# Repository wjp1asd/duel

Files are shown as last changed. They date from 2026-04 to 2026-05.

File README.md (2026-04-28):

# 🎴 DuelDisk-ESP32 | 决斗盘 ESP32

<p align="center">
  <strong>A Wi-Fi-controllable duel disk system powered by ESP32 & MicroPython</strong><br>
  基于 ESP32 + MicroPython 的 WiFi 控制智能决斗盘
</p>

---
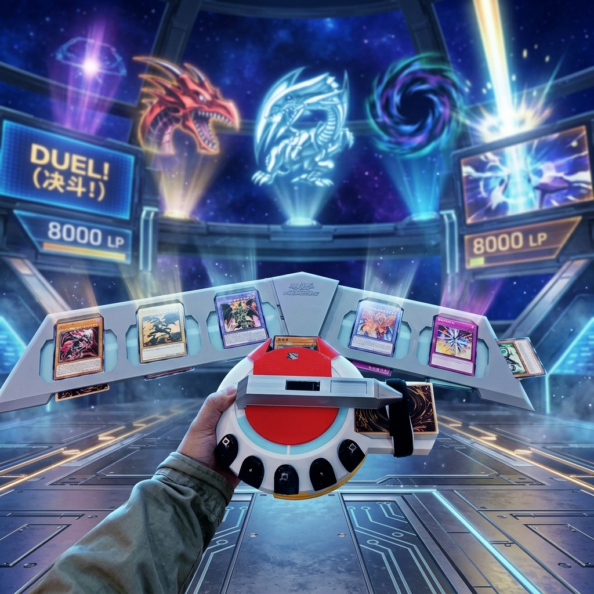
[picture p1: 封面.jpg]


## 🇨🇳 中文介绍

### 项目简介

本项目是一个基于 ESP32 的智能决斗盘系统，灵感来自经典卡牌对战游戏。通过 ESP32 微控制器集成 OLED 显示、舵机控制、音频播放、WS2812 灯光、RFID 读卡等功能，并通过 WiFi AP 模式提供网页控制界面，实现远程操控。
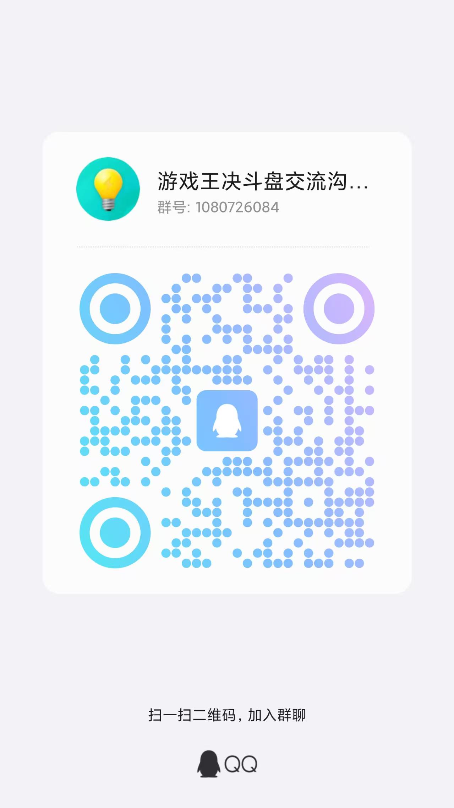
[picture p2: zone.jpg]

群里进行一些技术指导，和招募一些有能力的小伙伴，一起做智能眼镜终极版，早日完成童年梦想，同时也欢迎资源加入，如硬件供应，广告等，募集一些资金为爱发电。
虽然本项目开源，大家可以尽情创作，还是希望二道贩子可以声明一下出处，请等最终版发布再开始搬运。

音乐资源链接：https://pan.quark.cn/s/7ec613fa6839
### ✨ 功能特性

| 功能模块 | 说明 |
|---|---|
| 🖥️ OLED 显示 | SSD1306 128x32 OLED，支持 LP 生命值老虎机滚动动画 |
| 🎵 音频系统 | DFPlayer Mini，支持音效播放、随机背景音乐、音量调节 |
| 💡 WS2812 灯带 | 双灯带（各 30 珠），支持常亮 / 彩虹 / 呼吸 / 音乐闪烁 |
| 📡 WiFi 控制 | AP 热点模式（192.168.4.1），网页控制 LP、音乐、灯光、音量 |
| 🔧 舵机控制 | 机械爪开合控制 |
| 📋 RFID 读卡 | RC522 射频模块，支持 Mifare 1K 卡片 UID 读取 |

### 🔗 引脚分配

```
![](接线图.png)
┌─────────────────────────────────────────┐
│              ESP32 引脚映射              │
├─────────────┬─────────────┬─────────────┤
│    模块      │    引脚     │   GPIO      │
├─────────────┼─────────────┼─────────────┤
│ OLED SDA    │ I2C 数据    │ GPIO 5      │
│ OLED SCL    │ I2C 时钟    │ GPIO 17     │
│ DFPlayer TX │ UART 发送   │ GPIO 13     │
│ DFPlayer RX │ UART 接收   │ GPIO 12     │
│ WS2812 灯带1│ 数据        │ GPIO 27     │
│ WS2812 灯带2│ 数据        │ GPIO 14     │
└─────────────┴─────────────┴─────────────┘
```

### 📱 网页控制

连接 ESP32 的 WiFi 热点后，访问 `192.168.4.1` 即可打开控制面板：

- **LP 控制**：修改双方生命值，支持一键重置
- **音乐播放**：选择指定曲目或随机背景音乐
- **灯光模式**：切换灯带颜色和模式（常亮/彩虹/呼吸/关闭）
- **音量调节**：滑块 + 快捷按钮（±1/±5）

### 📁 项目结构

```
duel_project/
├── main.py          # 主程序（AP + Web Server + LED + 控制）
├── config.py        # 引脚与网络配置
├── audio.py         # DFPlayer Mini 音频控制
├── servo.py         # 舵机控制
├── oled_big.py      # OLED 大字体显示
├── ssd1306.py       # SSD1306 驱动
├── mfrc522.py       # RC522 RFID 驱动
├── rfid.py          # RFID 读卡逻辑
├── rmt.py           # 红外发射
├── boot.py          # 启动脚本
└── duel_net.py      # WiFi 网络模块（STA 模式预留）
```

### 🛠️ 快速开始

**1. 环境准备**
- ESP32 开发板
- MicroPython 固件（v1.28+）
- Thonny IDE 或 mpremote 工具

**2. 烧录固件**
```bash
esptool --port COM3 erase_flash
esptool --port COM3 --baud 460800 write_flash 0x1000 esp32-micropython.bin
```

**3. 上传代码**
```bash
ampy -p COM3 put main.py
ampy -p COM3 put config.py
ampy -p COM3 put audio.py
# ... 上传所有文件
```

**4. 连接使用**
- ESP32 启动后自动创建 WiFi 热点
- 手机/电脑连接该热点
- 浏览器访问 `192.168.4.1`

### 📦 硬件清单

- ESP32 开发板 ×1
- SSD1306 OLED 128×32 ×1
- DFPlayer Mini + 小喇叭 ×1
- SG90 舵机 ×1
- WS2812 灯带 ×2（各 30 珠）
- RC522 RFID 模块 ×1
- 按键开关 ×1
- 杜邦线若干

### 📄 许可证

MIT License

---

## 🇬🇧 English

### Overview

DuelDisk-ESP32 is a smart duel disk system built on ESP32 with MicroPython. Inspired by classic card battle games, it integrates OLED display, servo control, audio playback, WS2812 LED strips, RFID card reading, and a web-based control panel over WiFi AP mode.

### Features

| Module | Description |
|---|---|
| 🖥️ OLED Display | SSD1306 128×32, LP life points slot-machine scroll animation |
| 🎵 Audio | DFPlayer Mini, sound effects, random BGM, volume control |
| 💡 WS2812 LEDs | Dual strips (30 LEDs each), Solid / Rainbow / Breath / Music Flash |
| 📡 WiFi Control | AP hotspot (192.168.4.1), web UI for LP, music, LEDs, volume |
| 🔧 Servo | Mechanical gripper open/close control |
| 📋 RFID | RC522 module, Mifare 1K card UID reading |

### Pin Mapping

```
┌─────────────────────────────────────────┐
│            ESP32 Pin Mapping            │
├─────────────┬─────────────┬─────────────┤
│   Module    │   Signal    │   GPIO      │
├─────────────┼─────────────┼─────────────┤
│ OLED SDA    │ I2C Data    │ GPIO 5      │
│ OLED SCL    │ I2C Clock   │ GPIO 17     │
│ DFPlayer TX │ UART TX     │ GPIO 13     │
│ DFPlayer RX │ UART RX     │ GPIO 12     │
│ Servo       │ PWM Signal  │ GPIO 27     │
│ Button      │ Digital In  │ GPIO 14     │
│ WS2812 #1   │ Data        │ GPIO 27     │
│ WS2812 #2   │ Data        │ GPIO 14     │
└─────────────┴─────────────┴─────────────┘
```

### Web Control Panel

After connecting to the ESP32's WiFi hotspot, visit `192.168.4.1`:

- **LP Control**: Modify life points for both players, one-tap reset
- **Music**: Play specific tracks or random background music
- **LEDs**: Switch color and mode (Solid / Rainbow / Breath / Off)
- **Volume**: Slider + quick buttons (±1 / ±5)

### Project Structure

```
duel_project/
├── main.py          # Main program (AP + Web Server + LEDs + Control)
├── config.py        # Pin & network configuration
├── audio.py         # DFPlayer Mini audio controller
├── servo.py         # Servo motor controller
├── oled_big.py      # OLED large font display
├── ssd1306.py       # SSD1306 OLED driver
├── mfrc522.py       # RC522 RFID driver
├── rfid.py          # RFID card reading logic
├── rmt.py           # IR transmitter
├── boot.py          # Boot script
└── duel_net.py      # WiFi network module (STA mode reserved)
```

### Quick Start

**1. Prerequisites**
- ESP32 development board
- MicroPython firmware (v1.28+)
- Thonny IDE or mpremote tool

**2. Flash Firmware**
```bash
esptool --port COM3 erase_flash
esptool --port COM3 --baud 460800 write_flash 0x1000 esp32-micropython.bin
```

**3. Upload Code**
```bash
ampy -p COM3 put main.py
ampy -p COM3 put config.py
ampy -p COM3 put audio.py
# ... upload all files
```

**4. Connect & Play**
- ESP32 boots and creates a WiFi hotspot automatically
- Connect your phone or computer to the hotspot
- Open browser and navigate to `192.168.4.1`

### Bill of Materials

| Component | Quantity |
|---|---|
| ESP32 Dev Board | ×1 |
| SSD1306 OLED 128×32 | ×1 |
| DFPlayer Mini + Speaker | ×1 |
| SG90 Servo | ×1 |
| WS2812 LED Strip (30 LEDs) | ×2 |
| RC522 RFID Module | ×1 |
| Push Button | ×1 |
| DuPont Wires | As needed |

### License

MIT License

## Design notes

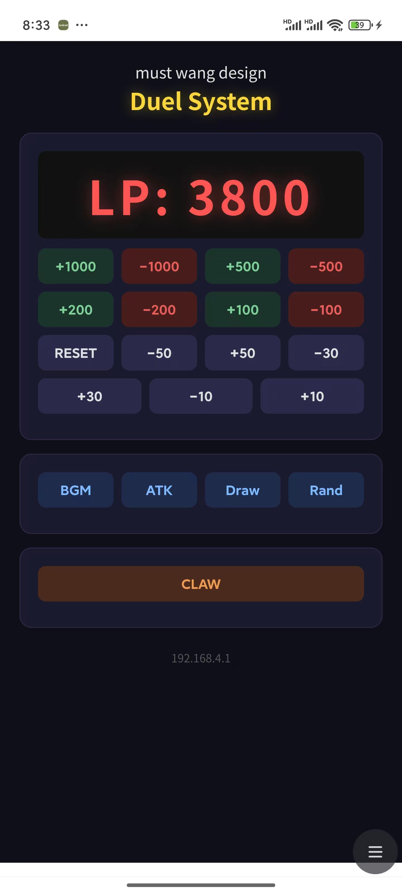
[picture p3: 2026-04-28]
photo.jpg

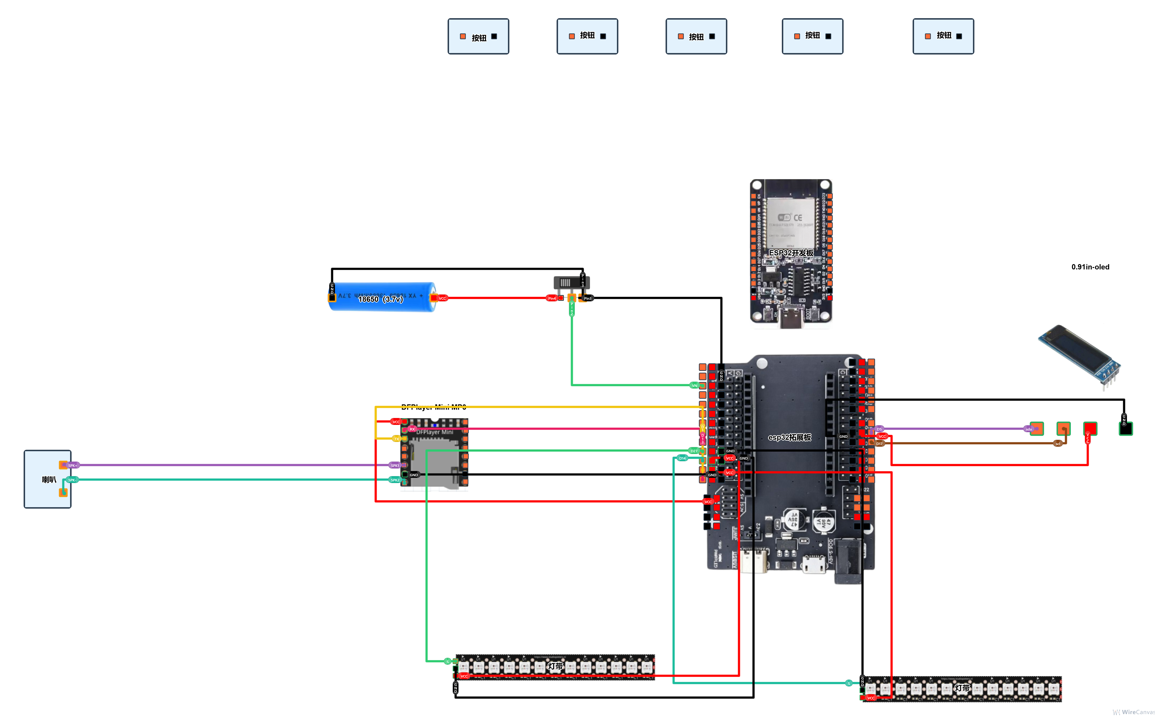
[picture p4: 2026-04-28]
接线图.png

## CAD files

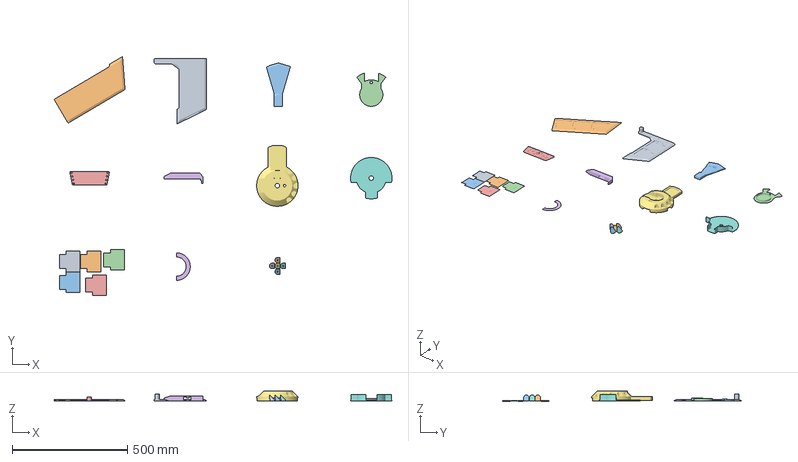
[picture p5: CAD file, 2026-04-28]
汇总.3mf
1468.0 x 1037.9 x 45.0 mm
镜向板2.STL
板1.STL
连接板.STL
盖板.STL
armreif2-v4.stl
显示屏支架.STL
圆盘底1.STL
底盖.STL
装饰1.STL x 5
圆环.STL
按钮.STL x 5

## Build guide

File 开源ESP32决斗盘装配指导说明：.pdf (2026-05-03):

# 开源 ESP32 决斗盘装配指导说明 V1.0：

一、成品效果：

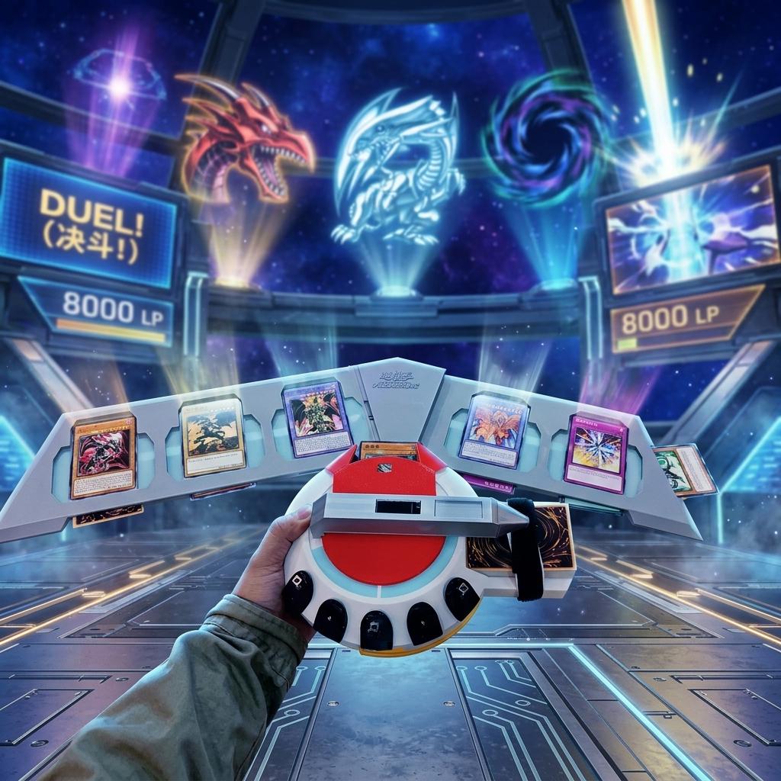
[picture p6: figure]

二、核心部件 BOM：（大家前期可以先自己买入）

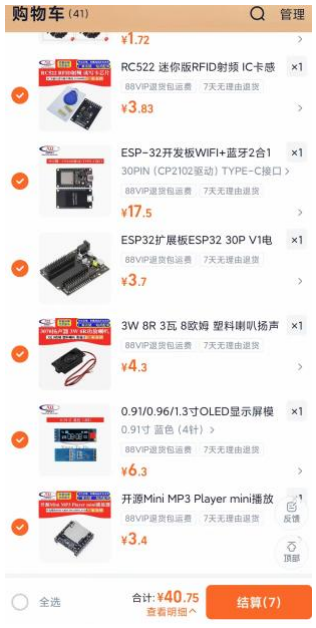
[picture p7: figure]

ps:这里如果有供应商可以提供零件包，可以联系我 17327697831(微信同号），进行合作

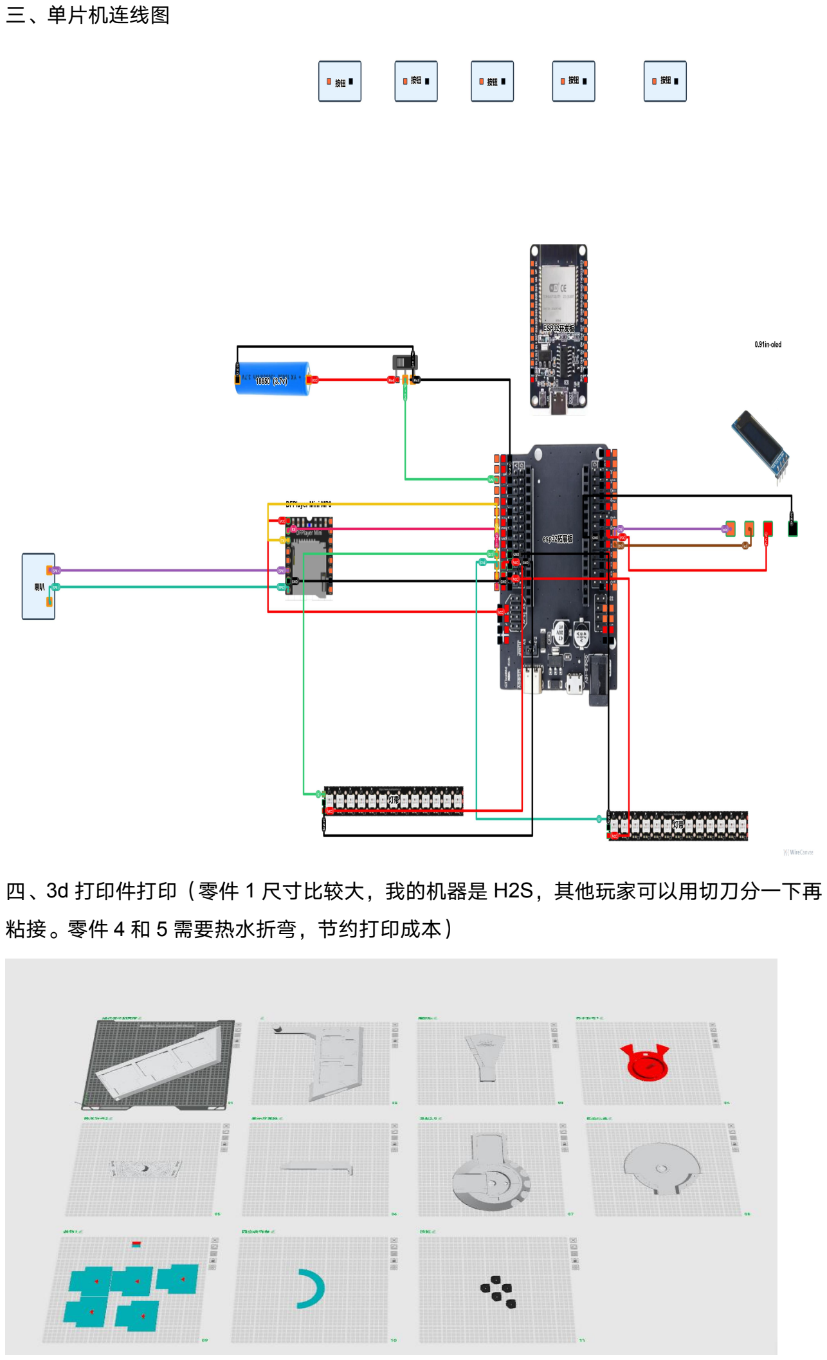
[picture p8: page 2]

三、单片机连线图

四、3d 打印件打印（零件 1 尺寸比较大，我的机器是 H2S，其他玩家可以用切刀分一下再 粘接。零件 4 和 5 需要热水折弯，节约打印成本）

四、开源链接&准备工作
GitHub：https://github.com/wjp1asd/duel<br/>makeworld:https://makerworld.com.cn/zh/models/2440812-you-xi-wang-jue-dou-pan-yu-g i-oh-duel-disk#profileId-2781842 (https://makerworld.com.cn/zh/models/2440812-you-xi-wang-jue-dou-pan-yu-gi-oh-duel-disk)

固件烧录 ：Thonny+MicroPython+ESP32 环境配置 - 知乎 (https://zhuanlan.zhihu.com/p/1919729439664734685) 固件也为大家准备好了，在目录下面。

配置好之后，将.py 文件导入 esp32 文件系统里运行即可。 内存卡资源配置：下载文件拖入内存中，这里遵守命名规则，后期也可以拓展其 他资源。

## 音乐资源链接：https://pan.quark.cn/s/7ec613fa6839

五、装配说明
1.以圆盘作为基础，正反面安装喇叭和 ESP32 -拓展版，使用 m3*5 左右的自攻螺钉，圆盘 预设安装孔位，如果没有螺钉子，热熔胶或 502 也可以。

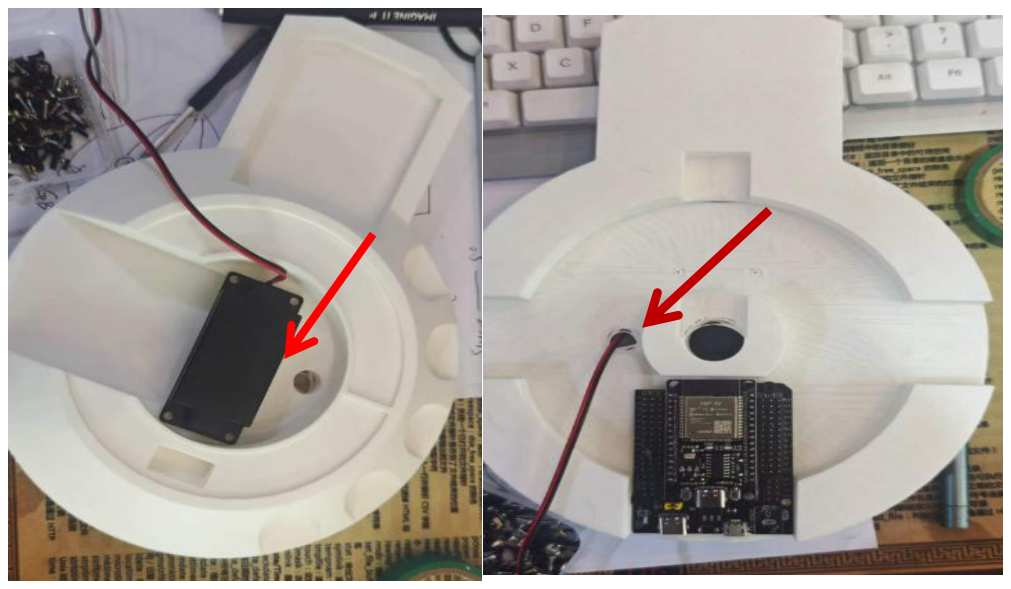
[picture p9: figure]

2. 参考接线图，完成 喇叭和 MP3 模块的安装，mp3 模块 4 条线分别从右图圆孔穿到背面。

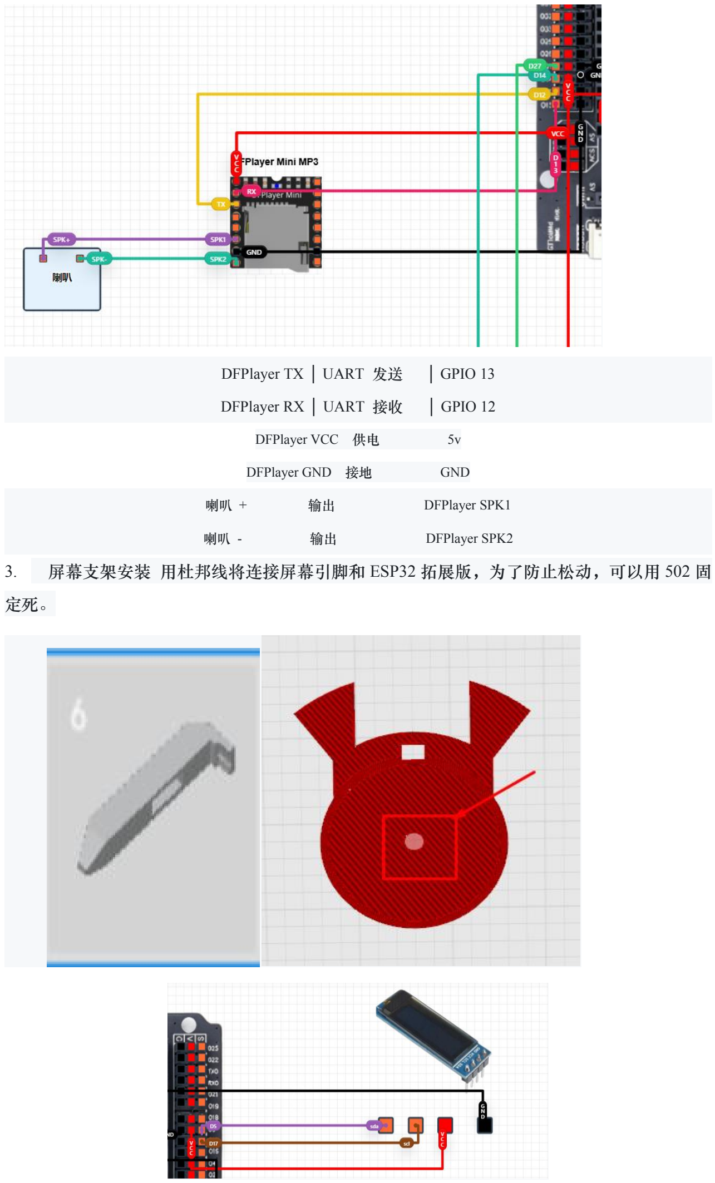
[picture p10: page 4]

DFPlayer TX │ UART | 发送 | │ GPIO 13
DFPlayer RX │ UART | 接收 | │ GPIO 12
DFPlayer VCC | 供电 | 5v DFPlayer GND | 接地 | GND
喇叭 | + | 输出 | DFPlayer SPK1
喇叭 | - | 输出 | DFPlayer SPK2
3. | 屏幕支架安装 | 用杜邦线将连接屏幕引脚和 ESP32 拓展版，为了防止松动，可以用 502 固
定死。

0.91oled│ sda | │ GPIO 5
0.91oled │ scl | │ GPIO 17
0.91oled | VCC | 供电 | 3.3v 0.91oled | GND | 接地 | GND

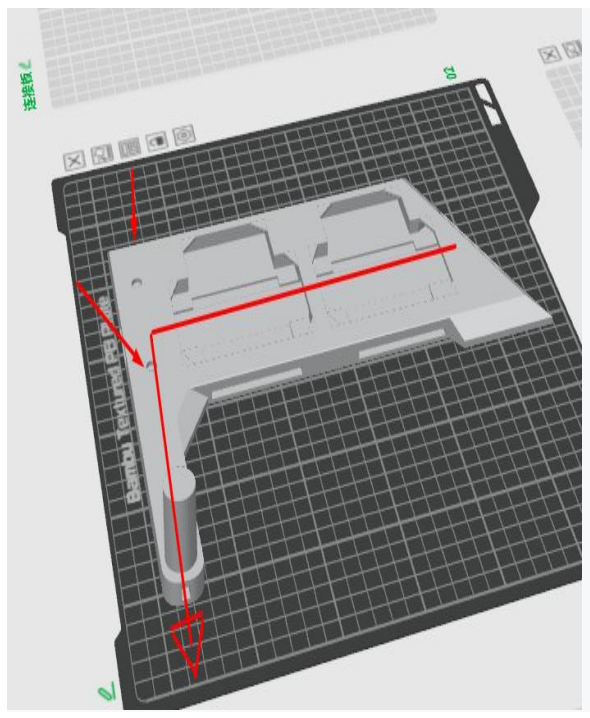
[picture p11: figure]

4. 战斗盘 LED 安装

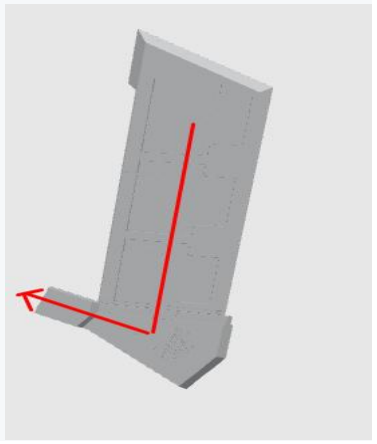
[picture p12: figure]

1. 先将盘 1 与连接板通过卡槽对应，led 灯带裁剪长度后，按照箭头方向，将三根导线从内部 通道穿出，用 502 胶水或者自攻螺钉加固成一个整体。
2. 同样将盘 1 灯带穿出，图示箭头位置，贴 6mm 圆形磁铁。（变形功能定位）

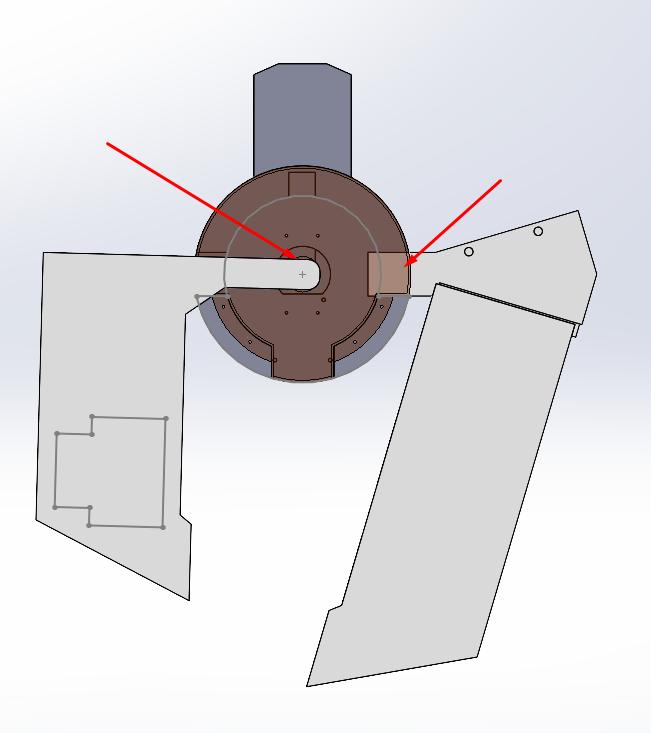
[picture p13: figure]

3. 按照接线图，接线与 ESP32 拓展板连接。

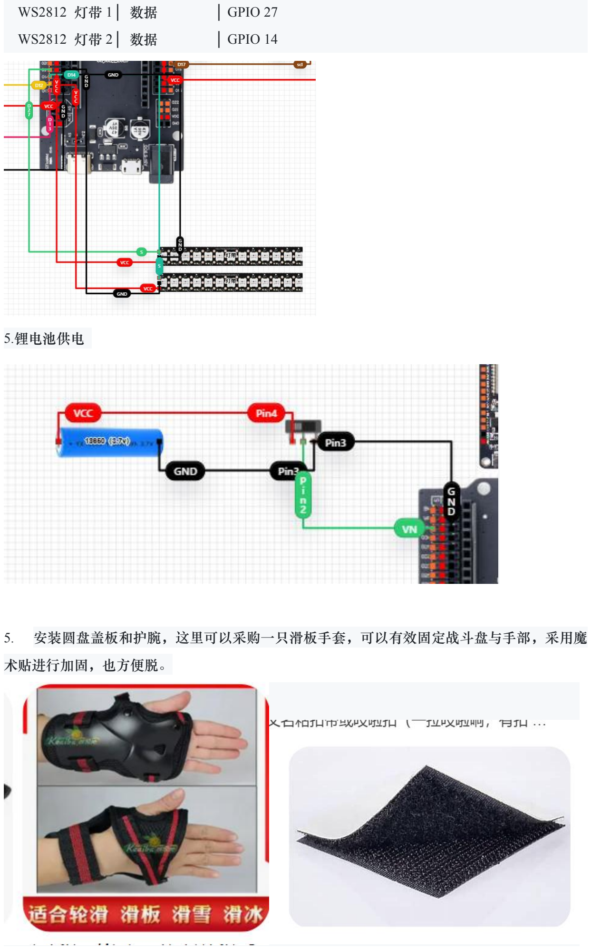
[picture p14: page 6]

WS2812 | 灯带 1│ | 数据 | │ GPIO 27
WS2812 | 灯带 2│ | 数据 | │ GPIO 14

5.锂电池供电

5. 安装圆盘盖板和护腕，这里可以采购一只滑板手套，可以有效固定战斗盘与手部，采用魔 术贴进行加固，也方便脱。

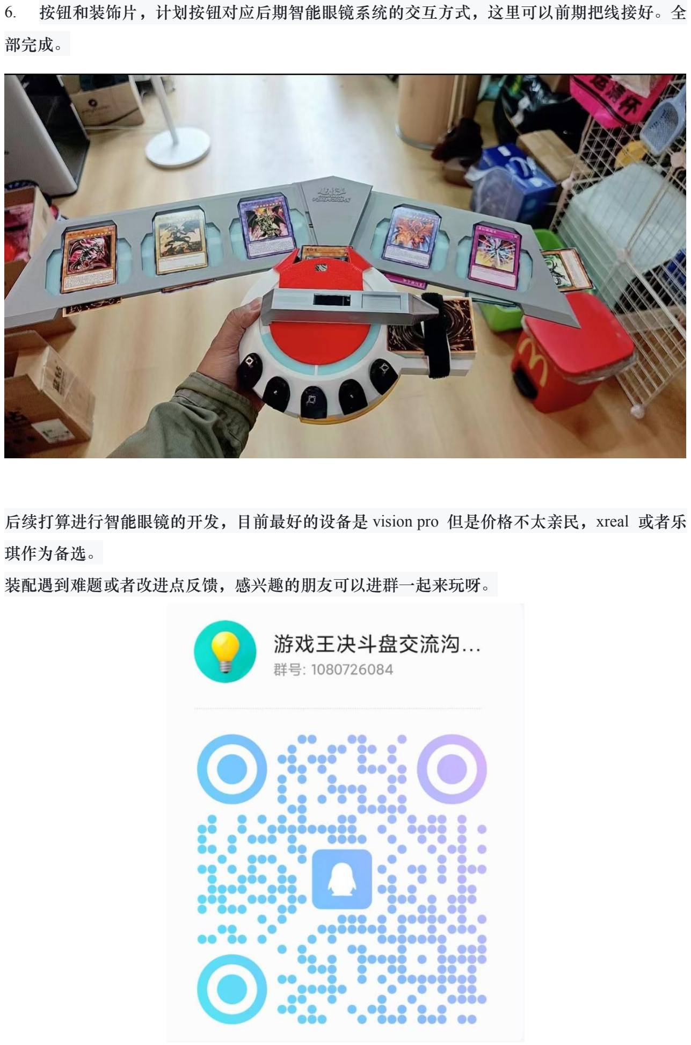
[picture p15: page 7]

6. 按钮和装饰片，计划按钮对应后期智能眼镜系统的交互方式，这里可以前期把线接好。全 部完成。
后续打算进行智能眼镜的开发，目前最好的设备是 vision pro | 但是价格不太亲民，xreal | 或者乐
琪作为备选。
装配遇到难题或者改进点反馈，感兴趣的朋友可以进群一起来玩呀。

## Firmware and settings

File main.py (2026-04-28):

# main.py - Duel System + WS2812 LED Control (GPIO26	 + GPIO25)
import network
import socket
import re
import utime
from machine import Pin
# from ir_rx.nec import NEC8
import random
try:
    import neopixel
    HAS_NEOPIXEL = True
except Exception as e:
    print("neopixel err:", e)
    HAS_NEOPIXEL = False

try:
    from oled_big import Oled_big
    from audio import Audio
    HAS_OLED  = True
    HAS_AUDIO = True
except Exception as e:
    print("Module load error:", e)
    HAS_OLED  = False
    HAS_AUDIO = False

# === WS2812 配置 ===
LED_N     = 30   # 每条灯带灯珠数量，按需修改
LED_PIN1  = 27   # 灯带1 GPIO
LED_PIN2  = 14   # 灯带2 GPIO
LED_BRIGHT = 0.6  # 全局亮度 0.0-1.0

# === LED 状态 ===
led1_mode  = "off"; led2_mode  = "off"
led1_r = 0; led1_g = 0; led1_b = 0
led2_r = 0; led2_g = 0; led2_b = 0
led1_bright = 1.0; led2_bright = 1.0
rainbow_step1 = 0; rainbow_step2 = 0
breath_v1 = 0.0; breath_v2 = 0.0
breath_dir1 = 1; breath_dir2 = 1
strip = 2  # 0=左, 1=右, 2=同时
led_flash = 0  # 音乐闪烁计数
led_flash_color = (0, 0, 255)  # 闪烁颜色 RGB
led_flash_count = 0  # 总闪烁帧数

def led_music_flash(frames=30, color=(0, 0, 255)):
    """播放音乐时触发LED闪烁"""
    global led_flash, led_flash_color, led_flash_count
    led_flash = frames
    led_flash_count = frames
    led_flash_color = color
    print("[LED flash] %d frames" % frames)

# === LED 对象 ===
np1 = None; np2 = None

def _np(pin, n):
    p = Pin(pin, Pin.OUT)
    p.value(0)
    return neopixel.NeoPixel(p, n)

def _apply(np, r, g, b):
    np.fill((int(r * LED_BRIGHT), int(g * LED_BRIGHT), int(b * LED_BRIGHT)))
    np.write()

def _rainbow(np, step):
    n = len(np)
    for i in range(n):
        h = (i * 256 // n + step) & 255
        if h < 85:
            np[i] = (int(LED_BRIGHT * (h * 3 // 85 * 85 // 3)), int(LED_BRIGHT * (255 - h * 3 // 85)), 0)
        elif h < 170:
            h -= 85
            np[i] = (0, int(LED_BRIGHT * (h * 3 // 85)), int(LED_BRIGHT * (255 - h * 3 // 85)))
        else:
            h -= 170
            np[i] = (int(LED_BRIGHT * (255 - h * 3 // 85)), 0, int(LED_BRIGHT * (h * 3 // 85)))
    np.write()

def _breath(np, v, r, g, b):
    np.fill((int(r * LED_BRIGHT * v), int(g * LED_BRIGHT * v), int(b * LED_BRIGHT * v)))
    np.write()

def led_tick1():
    global rainbow_step1, breath_v1, breath_dir1, led_flash
    # 音乐闪烁优先
    if led_flash > 0 and np1:
        flash_on = (led_flash % 6) < 3  # 每6帧切换，约100ms周期
        if flash_on:
            np1.fill(led_flash_color)
        else:
            np1.fill((0, 0, 0))
        np1.write()
        led_flash -= 1
        return
    # 普通模式
    if led1_mode == "solid":
        _apply(np1, led1_r, led1_g, led1_b)
    elif led1_mode == "rainbow":
        _rainbow(np1, rainbow_step1)
        rainbow_step1 = (rainbow_step1 + 2) & 255
    elif led1_mode == "breath":
        _breath(np1, breath_v1, led1_r, led1_g, led1_b)
        breath_v1 += 0.04 * breath_dir1
        if breath_v1 >= 1.0 or breath_v1 <= 0.05:
            breath_dir1 *= -1
    else:  # off
        if np1: np1.fill((0, 0, 0)); np1.write()

def led_tick2():
    global rainbow_step2, breath_v2, breath_dir2, led_flash
    # 音乐闪烁优先
    if led_flash > 0 and np2:
        flash_on = (led_flash % 6) < 3
        if flash_on:
            np2.fill(led_flash_color)
        else:
            np2.fill((0, 0, 0))
        np2.write()
        led_flash -= 1
        return
    if led2_mode == "solid":
        _apply(np2, led2_r, led2_g, led2_b)
    elif led2_mode == "rainbow":
        _rainbow(np2, rainbow_step2)
        rainbow_step2 = (rainbow_step2 + 2) & 255
    elif led2_mode == "breath":
        _breath(np2, breath_v2, led2_r, led2_g, led2_b)
        breath_v2 += 0.04 * breath_dir2
        if breath_v2 >= 1.0 or breath_v2 <= 0.05:
            breath_dir2 *= -1
    else:
        if np2: np2.fill((0, 0, 0)); np2.write()

# === 全局状态 ===
lifevalue   = 4000
musicindex    = 5
volume      = 20
music_queue = []
ir_cmd      = None
ap_ip       = "0.0.0.0"
AP_SSID     = "DuelAP"
AP_PASSWORD = ""

# === 外设对象 ===
oled  = None
audio = None

def start_ap():
    global ap_ip
    ap = network.WLAN(network.AP_IF)
    ap.active(True)
    ap.config(essid=AP_SSID)
    ap_ip = ap.ifconfig()[0]
    print("AP:", AP_SSID, " -> http://" + ap_ip)

def respond(sock, code, ct, body):
    if isinstance(body, str):
        body = body.encode("utf-8")
    hdr = ("HTTP/1.1 {}\r\nContent-Type: {}\r\nContent-Length: {}\r\n"
           "Connection: close\r\nAccess-Control-Allow-Origin: *\r\n\r\n").format(
               code, ct, len(body))
    try:
        sock.send(hdr.encode())
        sock.send(body)
    except:
        pass

def handle(path, method, body, addr):
    global lifevalue, music_queue, ir_cmd, volume, led_flash, led_flash_color
    global led1_mode, led2_mode, led1_r, led1_g, led1_b
    global led2_r, led2_g, led2_b, strip

    p = path.strip()

    if method == "GET" and p == "/lp":
        return "200", "application/json", '{"lp":%d,"ip":"%s"}' % (lifevalue, ap_ip)
    
    if method == "POST" and p == "/up":
         t =musicindex-1
         music_queue.append(t)
         return "302", "text/plain", ""
    
    if method == "POST" and p == "/down":
         t =musicindex+1
         music_queue.append(t)
         return "302", "text/plain", ""
    
    if method == "POST" and p == "/lp":
        m = re.search(r"lp=(\d+)", body)
        if m:
            lifevalue = max(0, min(9999, int(m.group(1))))
            if oled:
                try: oled.show_number_slot_machine(lifevalue)
                except: pass
            if audio:
                music_queue.append(2)
        return "302", "text/plain", ""

    if method == "POST" and p == "/lp_delta":
        m = re.search(r"delta=(-?\d+)", body)
        if m:
            lifevalue = max(0, min(9999, lifevalue + int(m.group(1))))
            if oled:
                try: oled.show_number_slot_machine(lifevalue)
                except: pass
            if audio:
                music_queue.append(2)
        return "302", "text/plain", ""

    m = re.match(r"/music/(\d+)", p)
    if m:
        t = int(m.group(1))
        if 1 <= t <= 30:
            music_queue.append(t)
        return "302", "text/plain", ""

    if method == "POST" and p == "/volume":
        m = re.search(r"n=(\d+)", body)
        if m and audio:
            try:
                vol = int(m.group(1))
                audio.set_volume(vol)
                volume = vol
            except Exception as e:
                print("Vol err:", e)
        return "302", "text/plain", ""

    if method == "GET" and p == "/volume":
        return "200", "application/json", '{"volume":%d}' % volume

    # LED 控制 POST /led
    if method == "POST" and p == "/led":
        m = re.search(r"strip=(\d)", body)
        m2 = re.search(r"mode=(\w+)", body)
        m3 = re.search(r"r=(\d+)", body)
        m4 = re.search(r"g=(\d+)", body)
        m5 = re.search(r"b=(\d+)", body)
        if m:  strip = int(m.group(1))
        if m2:
            mode = m2.group(1)
            if strip == 0 or strip == 2:
                led1_mode = mode
            if strip == 1 or strip == 2:
                led2_mode = mode
        if m3 and m4 and m5:
            r = int(m3.group(1)); g = int(m4.group(1)); b = int(m5.group(1))
            if strip == 0 or strip == 2:
                led1_r = r; led1_g = g; led1_b = b
            if strip == 1 or strip == 2:
                led2_r = r; led2_g = g; led2_b = b
        return "302", "text/plain", ""

    # LED 查询 GET /led
    if method == "GET" and p == "/led":
        return "200", "application/json", (
            '{"s1":{"mode":"%s","r":%d,"g":%d,"b":%d},'
            '"s2":{"mode":"%s","r":%d,"g":%d,"b":%d},'
            '"strip":%d}') % (
            led1_mode, led1_r, led1_g, led1_b,
            led2_mode, led2_r, led2_g, led2_b,
            strip)

    if method == "POST" and p == "/servo":
        return "302", "text/plain", ""

    if method == "GET" and p == "/ir":
        cmd = ir_cmd
        ir_cmd = None
        s = '"0x%02X"' % cmd if cmd is not None else "null"
        return "200", "application/json", '{"cmd":%s}' % s

    html = (HTML_PAGE
        .replace("__LP__", str(lifevalue))
        .replace("__VOL__", str(volume))
        .replace("__LED_MODE__", led1_mode)
        .replace("__LED_R__", str(led1_r))
        .replace("__LED_G__", str(led1_g))
        .replace("__LED_B__", str(led1_b)))
    return "200", "text/html; charset=utf-8", html

HTML_PAGE = """<!DOCTYPE html>
<html lang="zh">
<head>
<meta charset="utf-8">
<meta name="viewport" content="width=device-width,initial-scale=1">
<title>Duel Control</title>
<style>
*{box-sizing:border-box;margin:0;padding:0}
body{font-family:'Segoe UI',sans-serif;background:#0f0f1a;color:#e0e0e0;
  min-height:100vh;display:flex;flex-direction:column;align-items:center;padding:20px}
h1{font-size:1.5em;margin-bottom:16px;color:#ffd700;text-shadow:0 0 12px rgba(255,215,0,.4)}
.card{background:#1a1a2e;border:1px solid #2a2a4a;border-radius:12px;
  padding:18px;width:100%;max-width:400px;margin-bottom:14px}
.lp{font-size:3em;font-weight:bold;text-align:center;color:#ff4d4d;
  text-shadow:0 0 16px rgba(255,77,77,.5);background:#111;padding:10px 20px;
  border-radius:8px;margin-bottom:10px;letter-spacing:4px}
.row{display:flex;gap:8px;flex-wrap:wrap;justify-content:center;margin-bottom:8px}
button{flex:1;min-width:70px;padding:9px 4px;border:none;border-radius:8px;
  font-size:.86em;cursor:pointer;font-weight:bold;transition:all .15s}
.lp-btn{background:#2a2a4a;color:#e0e0e0}
.lp-btn:hover{background:#3a3a6a}
.lp-btn.g{background:#14332a;color:#6fcf97}
.lp-btn.r{background:#4a1b1b;color:#eb5757}
.mu{background:#1b2a4a;color:#74b9ff}
.mu:hover{background:#2a3a6a}
.sv{background:#4a2a1b;color:#f2994a}
.sv:hover{background:#6a3a2b}
.color-btn{background:#1a1a2e;border:2px solid #2a2a4a;color:#fff;padding:7px 2px}
.color-btn:hover{border-color:#555}
.color-btn.active{border-color:#ffd700}
.color-btn.on{background:#2a2a4a;border-color:#ffd700}
#t{position:fixed;top:10px;right:10px;background:#1b4332;color:#6fcf97;
  padding:7px 14px;border-radius:6px;font-size:.84em;display:none;transition:opacity:.3s}
.info{font-size:.72em;color:#555;text-align:center;margin-top:8px}
.led-strip{display:flex;gap:6px;margin-bottom:10px}
.strip-btn{padding:6px 12px;border:none;border-radius:6px;font-size:.8em;
  cursor:pointer;background:#2a2a4a;color:#aaa;font-weight:bold}
.strip-btn.active{background:#ffd700;color:#111}
.mode-row{display:flex;gap:6px;margin-bottom:10px}
.mode-btn{padding:7px 4px;flex:1;border:none;border-radius:6px;font-size:.78em;
  cursor:pointer;background:#2a2a4a;color:#aaa;font-weight:bold;text-align:center}
.mode-btn.active{background:#4a2a8a;color:#c9a0ff}
.color-pick{margin-bottom:10px}
.color-pick label{font-size:.8em;color:#aaa;margin-right:6px}
.color-pick input[type=range]{flex:1;accent-color:#ffd700}
.color-pick span{font-size:.8em;color:#fff;min-width:30px;text-align:center}
.preset-row{display:flex;gap:6px;flex-wrap:wrap;margin-bottom:6px}
</style>
</head>
<body>
<h1>Duel System</h1>
<h2>Must Design</h2>
<div class="card">
  <div class="lp" id="lp">LP: __LP__</div>
  <div class="row">
    <button class="lp-btn g" onclick="delta(+1000)">+1000</button>
    <button class="lp-btn r" onclick="delta(-1000)">-1000</button>
    <button class="lp-btn g" onclick="delta(+500)">+500</button>
    <button class="lp-btn r" onclick="delta(-500)">-500</button>
    <button class="lp-btn g" onclick="delta(+200)">+200</button>
    <button class="lp-btn r" onclick="delta(-200)">-200</button>
    <button class="lp-btn g" onclick="delta(+100)">+100</button>
    <button class="lp-btn r" onclick="delta(-100)">-100</button>
  </div>
  <div class="row">
    
    <button class="lp-btn" onclick="delta(50)">+50</button>
    <button class="lp-btn" onclick="delta(-50)">-50</button>
    <button class="lp-btn" onclick="delta(10)">+10</button>
    <button class="lp-btn" onclick="delta(-10)">-10</button>
     <button class="lp-btn" onclick="delta(5)">+5</button>
    <button class="lp-btn" onclick="delta(-5)">-5</button>
     <button class="lp-btn" onclick="delta(1)">+1</button>
    <button class="lp-btn" onclick="delta(-1)">-1</button>
    <button class="lp-btn" onclick="setlp(4000)">RESET</button>
  </div>
</div>
<div class="card">
  <div style="text-align:center;margin-bottom:8px;color:#aaa;font-size:.85em">Volume</div>
  <div class="row">
    <button class="mu" onclick="vol(-5)">-5</button>
    <button class="mu" onclick="vol(-1)">-1</button>
    <span id="vol" style="flex:1;text-align:center;line-height:36px;font-weight:bold;color:#74b9ff">__VOL__</span>
    <button class="mu" onclick="vol(1)">+1</button>
    <button class="mu" onclick="vol(5)">+5</button>
  </div>
</div>
<div class="card">
<div style="text-align:center;margin-bottom:8px;color:#aaa;font-size:.85em">Music</div>

  <div class="row">
    <button class="mu" onclick="mu(1)">BGM</button>
    <button class="mu" onclick="mu(2)">ATK</button>
    <button class="mu" onclick="mu(3)">Draw</button>
    <button class="mu" onclick="up()">UP</button>
    <button class="mu" onclick="down()">DOWN</button>
    <button class="mu" onclick="mu(5)">Rand</button>
  </div>
</div>

<div class="card">
<div style="text-align:center;margin-bottom:8px;color:#aaa;font-size:.85em">Action</div>
  <div class="row">
    <button class="sv" onclick="sv()">CLAW</button>
  </div>
</div>



<div class="card">
  <div style="text-align:center;margin-bottom:10px;color:#ffd700;font-size:.9em;font-weight:bold">LED Strip</div>
  <div class="led-strip">
    <button class="strip-btn active" id="btn-s0" onclick="setStrip(0)">GPIO33</button>
    <button class="strip-btn" id="btn-s1" onclick="setStrip(1)">GPIO25</button>
    <button class="strip-btn" id="btn-s2" onclick="setStrip(2)">BOTH</button>
  </div>
  <div class="mode-row">
    <button class="mode-btn active" id="btn-off" onclick="setMode('off')">OFF</button>
    <button class="mode-btn" id="btn-solid" onclick="setMode('solid')">SOLID</button>
    <button class="mode-btn" id="btn-rainbow" onclick="setMode('rainbow')">RAINBOW</button>
    <button class="mode-btn" id="btn-breath" onclick="setMode('breath')">BREATH</button>
  </div>
  <div class="preset-row">
    <button class="color-btn" style="background:#ff0000" onclick="setColor(255,0,0)">R</button>
    <button class="color-btn" style="background:#ff8800" onclick="setColor(255,136,0)">O</button>
    <button class="color-btn" style="background:#ffff00" onclick="setColor(255,255,0)">Y</button>
    <button class="color-btn" style="background:#00ff00" onclick="setColor(0,255,0)">G</button>
    <button class="color-btn" style="background:#00ffff" onclick="setColor(0,255,255)">C</button>
    <button class="color-btn" style="background:#0088ff" onclick="setColor(0,136,255)">B</button>
    <button class="color-btn" style="background:#8800ff" onclick="setColor(136,0,255)">P</button>
    <button class="color-btn" style="background:#ff00ff" onclick="setColor(255,0,255)">M</button>
    <button class="color-btn" style="background:#ffffff" onclick="setColor(255,255,255)">W</button>
    <button class="color-btn" style="background:#ff0044" onclick="setColor(255,0,68)">RD</button>
  </div>
  <div class="color-pick" id="colorPick">
    <div class="row" style="margin-bottom:4px">
      <label>R</label>
      <input type="range" id="r" min="0" max="255" value="__LED_R__">
      <span id="rv">__LED_R__</span>
    </div>
    <div class="row" style="margin-bottom:4px">
      <label>G</label>
      <input type="range" id="g" min="0" max="255" value="__LED_G__">
      <span id="gv">__LED_G__</span>
    </div>
    <div class="row">
      <label>B</label>
      <input type="range" id="b" min="0" max="255" value="__LED_B__">
      <span id="bv">__LED_B__</span>
    </div>
  </div>
</div>

<div id="t"></div>
<div class="info" id="info">--</div>

<script>
var lp = __LP__;
var curStrip = 2;
var curMode = '__LED_MODE__';
var curR = __LED_R__, curG = __LED_G__, curB = __LED_B__;
function $(id){return document.getElementById(id);}
function t(msg){var e=$('t');e.textContent=msg;e.style.display='block';setTimeout(function(){e.style.display='none'},1800);}
function r(){fetch('/lp').then(function(x){return x.json()}).then(function(d){lp=d.lp;$('lp').textContent='LP: '+lp;$('info').textContent=d.ip}).catch(function(){})}
function delta(d){lp=Math.max(0,Math.min(9999,lp+d));$('lp').textContent='LP: '+lp;
  fetch('/lp_delta',{method:'POST',headers:{'Content-Type':'application/x-www-form-urlencoded'},body:'delta='+d}).then(function(){t('LP: '+lp)}).catch(function(){})}
function setlp(v){lp=v;$('lp').textContent='LP: '+lp;
  fetch('/lp',{method:'POST',headers:{'Content-Type':'application/x-www-form-urlencoded'},body:'lp='+v}).then(function(){t('LP: '+v)}).catch(function(){})}
function mu(n){fetch('/music/'+n).then(function(){t('Track '+n)}).catch(function(){})}
function up(){fetch('/up',{method:'POST'}).then(function(){t('up')}).catch(function(){})}
function down(){fetch('/down',{method:'POST'}).then(function(){t('down')}).catch(function(){})}
function sv(){fetch('/servo',{method:'POST'}).then(function(){t('Claw!')}).catch(function(){})}
function vol(d){var v=$('vol');var x=parseInt(v.textContent)+d;x=Math.max(0,Math.min(30,x));v.textContent=x;
  fetch('/volume',{method:'POST',headers:{'Content-Type':'application/x-www-form-urlencoded'},body:'n='+x}).then(function(){t('Vol: '+x)}).catch(function(){})}
function ledCmd(mode,r,g,b){
  fetch('/led',{method:'POST',headers:{'Content-Type':'application/x-www-form-urlencoded'},
    body:'strip='+curStrip+'&mode='+mode+'&r='+r+'&g='+g+'&b='+b}).then(function(){t(mode+' ('+r+','+g+','+b+')')}).catch(function(){})}
function setStrip(s){curStrip=s;
  document.querySelectorAll('.strip-btn').forEach(function(b){b.classList.remove('active')});
  $('btn-s'+s).classList.add('active');
  document.getElementById('colorPick').style.display=s===2?'none':'block';}
function setMode(m){curMode=m;
  document.querySelectorAll('.mode-btn').forEach(function(b){b.classList.remove('active')});
  $('btn-'+m).classList.add('active');
  ledCmd(m,curR,curG,curB);}
function setColor(r,g,b){curR=r;curG=g;curB=b;
  $('r').value=r;$('g').value=g;$('b').value=b;
  $('rv').textContent=r;$('gv').textContent=g;$('bv').textContent=b;
  if(curMode==='solid'){ledCmd('solid',r,g,b);}else{curMode='solid';setMode('solid');}}
['r','g','b'].forEach(function(c){
  var el = $(c);
  el.addEventListener('input',function(){
    var v=this.value;
    if(c==='r'){$('rv').textContent=v;curR=parseInt(v);}
    if(c==='g'){$('gv').textContent=v;curG=parseInt(v);}
    if(c==='b'){$('bv').textContent=v;curB=parseInt(v);}
    if(curMode==='solid'){ledCmd('solid',curR,curG,curB);}
  });
});
setInterval(r,2000);r();
</script>
</body>
</html>"""

def ir_callback(cmd, addr, nec):
    global ir_cmd
    ir_cmd = cmd
    print("[IR] 0x%02X" % cmd)

def main():
    global lifevalue, volume, music_queue, oled, audio
    global np1, np2, led1_mode, led2_mode

    print("=== Duel System vLED ===")
    start_ap()

    # 初始化 WS2812
    if HAS_NEOPIXEL:
        try:
            np1 = _np(LED_PIN1, LED_N)
            np2 = _np(LED_PIN2, LED_N)
            print("LED: GPIO%d+%dx%d OK" % (LED_PIN1, LED_PIN2, LED_N))
        except Exception as e:
            print("LED init err:", e)
    else:
        print("LED: neopixel not available")

    oled  = Oled_big() if HAS_OLED else None
    audio = Audio()    if HAS_AUDIO else None
    if audio:
        audio.set_volume(volume)
       # audio.play_music1(1)
    if oled:
        oled.show_number_slot_machine(lifevalue)
# 
#     try:
#         NEC8(Pin(15, Pin.IN), ir_callback)
#         print("IR OK on GPIO15")
#     except Exception as e:
#         print("IR err:", e)

    sock = None
    try:
        sock = socket.socket()
        sock.setsockopt(socket.SOL_SOCKET, socket.SO_REUSEADDR, 1)
        sock.bind(("0.0.0.0", 80))
        sock.listen(1)
        sock.settimeout(0.1)
        print("HTTP server ready")
    except Exception as e:
        print("Socket err:", e)

    tick = 0
    while True:
        # LED 动画（非阻塞，每帧更新）
        if tick % 4 == 0:
            if np1: led_tick1()
            if np2: led_tick2()
        tick += 1

        # HTTP 请求处理
        if sock:
            try:
                cl, addr = sock.accept()
                cl.settimeout(1.0)
                try:
                    d = cl.recv(1024).decode("utf-8", "ignore")
                    if d:
                        lines = d.split("\r\n")
                        req   = lines[0].split()
                        m     = req[0]
                        p     = req[1] if len(req) > 1 else "/"
                        body  = ""
                        idx   = d.find("\r\n\r\n")
                        if idx >= 0:
                            body = d[idx + 4:]
                        code, ct, bdy = handle(p, m, body, addr)
                        respond(cl, code, ct, bdy)
                except Exception as e:
                    print("Req err:", e)
                finally:
                    try: cl.close()
                    except: pass
            except OSError:
                pass

        # 音乐队列
        if music_queue and audio:
            t = music_queue.pop(0)
            led_music_flash(15, (random.randint(0, 255),random.randint(0, 255), 255))  # 音乐响LED闪烁30帧
            try:
                    if 1 <= t <= 4:
                       audio.play_music1(t)
                    else:
                       audio.play_bgmusic()     
            except Exception as e:
                    print("Audio err:", e)
            utime.sleep_ms(80)

        utime.sleep_ms(10)

if __name__ == "__main__":
    main()

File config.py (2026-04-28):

# config.py - 项目配置

# === WiFi 配置 ===
WIFI_SSID = "YourWiFiSSID"
WIFI_PASSWORD = "YourWiFiPassword"

# === App 通信配置 ===
APP_HOST = "192.168.1.100"  # Android App IP（动态获取或固定）
APP_PORT = 8888

# === I2C 配置 (OLED) ===
I2C_SDA = 5
I2C_SCL = 17
I2C_FREQ = 400000

# # === I2S 配置 (MAX98357A 音频) ===
# I2S_BCLK = 12   # 位时钟
# I2S_LRC = 14    # 左右声道时钟
# I2S_DIN = 13    # 数据输入

DFPLAYER_UART = 1
DFPLAYER_TX = 13
DFPLAYER_RX = 12
DFPLAYER_BUSY_PIN = None  # 可选 BUSY 引脚，不接则留 None


# === SPI 配置 (RC522 射频卡) ===
SPI_SCK = 15
SPI_MOSI = 2
SPI_MISO = 4
SPI_CS = 16
RFID_RST = 0

# === OLED 配置 ===
OLED_WIDTH = 128
OLED_HEIGHT = 32
# === 舵机 配置 ===
SERVO_PIN =27

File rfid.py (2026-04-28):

# RC522 测试 - 引脚: SDA=16, SCK=15, MOSI=2, MISO=4, RST=17
from machine import Pin, SPI
import utime

SDA = 16 # CS
SCK = 15 # SCK
MOSI = 2 # MOSI
MISO = 4 # MISO
RST = 21 # RST

# SPI 初始化
spi = SPI(
 1,
 baudrate=1000000,
 polarity=0,
 phase=0,
 sck=Pin(SCK),
 mosi=Pin(MOSI),
 miso=Pin(MISO)
)
print("SPI1 OK sck=%d mosi=%d miso=%d" % (SCK, MOSI, MISO))

# RC522 初始化
try:
     from mfrc522 import MFRC522
     rdr = MFRC522(Pin(SCK), Pin(MOSI), Pin(MISO), Pin(RST), Pin(SDA))
     print("MFRC522 OK sda=%d sck=%d mosi=%d miso=%d rst=%d" % (SDA, SCK, MOSI, MISO, RST))
except Exception as e:
     print("mfrc522 ERR:", e)
     raise

print("\n=== 刷卡测试 ===")
LED = Pin(13, Pin.OUT)
LED.value(0)

while True:
 try:
     stat, uid = rdr.read_card()
     if stat == rdr.OK and uid:
         uid_str = ':'.join('%02X' % b for b in uid)
         print(">>> CARD: " + uid_str)
         for _ in range(3):
             LED.toggle()
             utime.sleep_ms(100)
             LED.value(0)
             utime.sleep_ms(80)
 except Exception as e:
     print("Err:", e)
 utime.sleep_ms(500)

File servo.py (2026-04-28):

from machine import Pin, PWM
import time

# ========== 配置区 ==========
SERVO_PIN = 15        # 修改为你的实际引脚
FREQ = 50             # 标准舵机频率50Hz

# 不同舵机的脉宽范围可能不同
MIN_US = 500          # 0度脉宽 (0.5ms)
MAX_US = 2500         # 180度脉宽 (2.5ms)
# 如果无反应，尝试改为: MIN_US=1000, MAX_US=2000 (SG90常见)

# 计算duty (ESP32 duty范围0-1023对应0%-100%)
def us_to_duty(us):
    return int(us / 20000 * 1023)  # 20ms周期 = 20000us

# 初始化
servo = PWM(Pin(SERVO_PIN), freq=FREQ)

print(f"舵机测试 - 引脚GPIO{SERVO_PIN}, 频率{FREQ}Hz")
print(f"0度 duty={us_to_duty(MIN_US)}, 180度 duty={us_to_duty(MAX_US)}")

# 测试1: 直接输出中间位置
print("\n测试1: 90度位置")
servo.duty(us_to_duty(1500))  # 1500us = 90度
time.sleep(1)

# 测试2: 缓慢扫描
print("测试2: 0->180->0扫描")
try:
    while True:
        # 0度
        print(" -> 0度")
        servo.duty(us_to_duty(MIN_US))
        time.sleep(1)
        
        # 90度
        print(" -> 90度")
        servo.duty(us_to_duty(1500))
        time.sleep(1)
        
        # 180度
        print(" -> 180度")
        servo.duty(us_to_duty(MAX_US))
        time.sleep(1)
        
        # 回90度
        print(" -> 90度")
        servo.duty(us_to_duty(1500))
        time.sleep(1)
        
except KeyboardInterrupt:
    print("\n停止")
    servo.deinit()  # 释放PWM 
